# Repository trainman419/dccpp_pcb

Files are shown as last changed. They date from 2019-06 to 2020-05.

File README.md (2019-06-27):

# DCC++ PCB - All the parts for a basic DCC++ command station on a single PCB

This is the DCC++ board project. It's a relatively simple printed circuit board which integrates all of the components that are necessary for a DCC++ base station onto a single PCB, with all of the things you need, and nothing you don't.

Instead of the typical 1A limit of the arduino motor shield, this board uses the IFX007T half-bridge, with much larger current and voltage capability (up to 24V). Current capacity (without a heatsink) is probably around 5A, but may be more with proper ventilation or heatsinking.

The board is roughly based on the [Arduino Leonardo](https://www.arduino.cc/en/Main/Arduino_BoardLeonardo) and [Sparkfun's Pro Micro board](https://www.sparkfun.com/products/12640), but with the outputs already wired to the correct pins on IFX007T. The unused pins are available on screw terminals.

I designed this board to support the current and voltage needs of a G scale railroad, but it should work equally well for smaller scales.

The LEDs are connected to Arduino pins D1 and D2.

# Initial Programming

 * Attach an AVR ISP programming dongle, USBtiny, or other AVR programmer to your PC and board. (Make sure the drivers are installed).
 * Power on the DCC++ board by plugging in the micro USB cable.
 * Open the Arduino IDE
 * In the Tools menu, select "Arduino Leonardo" as the board type
 * In the Tools menu, select your programmer
 * In the Tools menu, select "Burn Bootloader"
 * Wait for the bootloader to complete. The board should show up as a serial port after the bootloader is flashed.
 * Clone my fork of the DCC++ project and load the DCCpp_Uno sketch onto the board.
 * Done!

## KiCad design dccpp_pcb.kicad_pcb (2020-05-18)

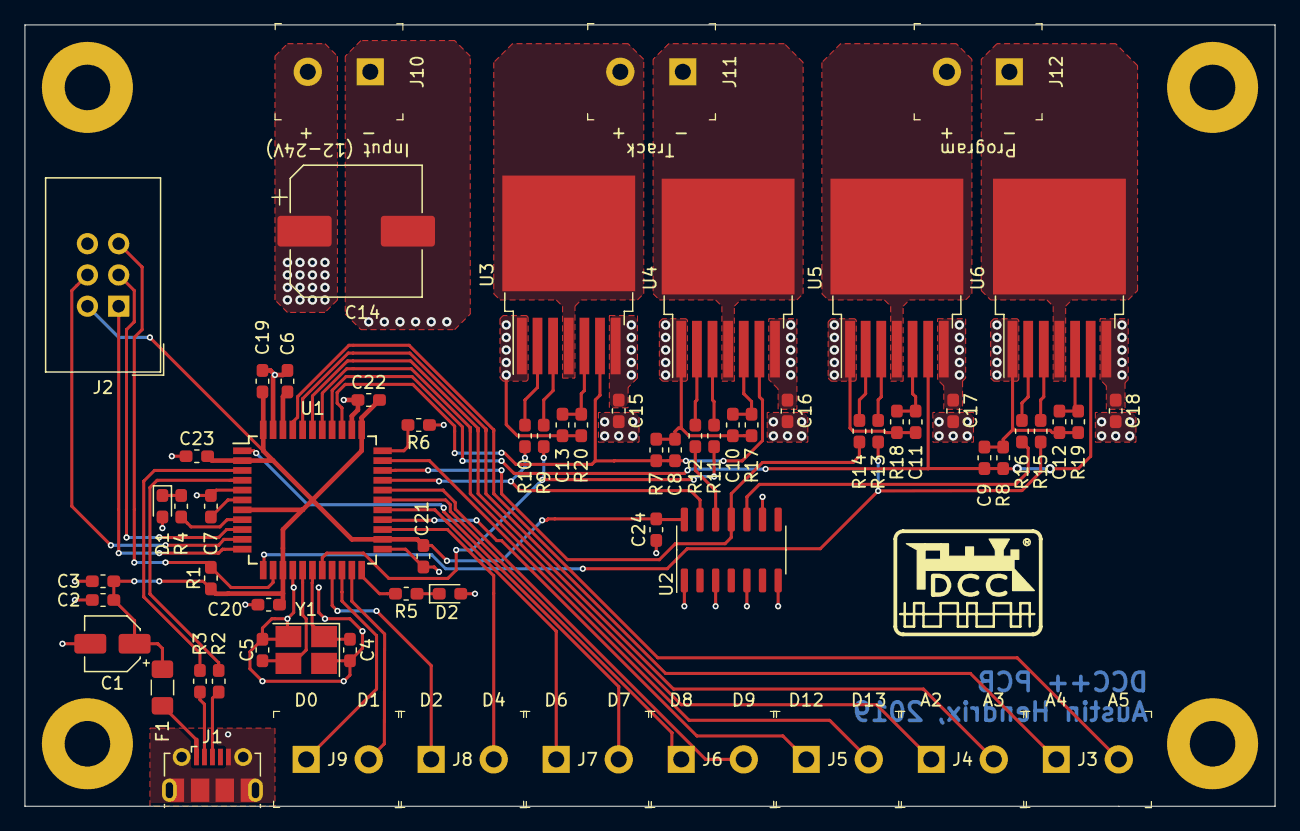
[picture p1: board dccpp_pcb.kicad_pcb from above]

Board: 2 copper layers, 101.6 x 63.5 mm, 66 parts (0 on the bottom side), 59 nets.

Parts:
C1: 10uF; CP_Elec_4x5.4
C2, C6, C10, C11, C12, C13, C19, C20, C21, C22, C23, C24: 0.1uF 10V; C_0603_1608Metric_Pad1.05x0.95mm_HandSolder
C3, C7: 1uF 10V; C_0603_1608Metric_Pad1.05x0.95mm_HandSolder
C4, C5: 22pF 10V; C_0603_1608Metric_Pad1.05x0.95mm_HandSolder
C8, C9: 1000pF 10V; C_0603_1608Metric_Pad1.05x0.95mm_HandSolder
C14: 100uF 30V; CP_Elec_10x10.5
C15, C16, C17, C18: 0.1uF 30V; C_0603_1608Metric_Pad1.05x0.95mm_HandSolder
D1: LED (Yellow); LED_0603_1608Metric_Pad1.05x0.95mm_HandSolder
D2: LED (Green); LED_0603_1608Metric_Pad1.05x0.95mm_HandSolder
F1: 500mA cont / 1A trip; Fuse_1206_3216Metric_Pad1.42x1.75mm_HandSolder
J1: USB_B_Micro; USB_Micro-B_Molex-105017-0001
J2: AVR-ISP-6; IDC-Header_2x03_P2.54mm_Vertical
J3, J4, J5, J6, J7, J8, J9, J10, J11, J12: OSTTC022162; Term_Block_1x2_P5.08MM
R1, R6, R9, R10, R11, R12, R13, R14, R15, R16: 10k; R_0603_1608Metric_Pad1.05x0.95mm_HandSolder
R2, R3: 22; R_0603_1608Metric_Pad1.05x0.95mm_HandSolder
R4, R5: 330; R_0603_1608Metric_Pad1.05x0.95mm_HandSolder
R7, R8: 470; R_0603_1608Metric_Pad1.05x0.95mm_HandSolder
R17, R18, R19, R20: 510; R_0603_1608Metric_Pad1.05x0.95mm_HandSolder
U1: ATmega32U4-AU; TQFP-44_10x10mm_P0.8mm
U2: 74HC04; SOIC-14_3.9x8.7mm_P1.27mm
U3, U4, U5, U6: IFX007T; TO-263-7_TabPin8
Y1: 16MHz; Crystal_SMD_SeikoEpson_TSX3225-4Pin_3.2x2.5mm_HandSoldering

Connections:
+5V: C1.1, C2.2, C3.2, C19.2, C20.2, C21.2, C22.2, C23.2, C24.2, F1.1, J2.2, R1.2, U1.2, U1.7, U1.14, U1.24, U1.34, U1.44, U2.14
/A2: J4.1, U1.38
/A3: J4.2, U1.39
/A4: J3.1, U1.40
/A5: J3.2, U1.41
/D0: J9.1, U1.20
/D1: J9.2, U1.21
/D2: J8.1, U1.19
/D4: J8.2, U1.25
/D6: J7.1, U1.27
/D7: J7.2, U1.1
/D8: J6.1, U1.28
/D9: J6.2, U1.29
/D12: J5.1, U1.26
/D13: J5.2, U1.32
/MISO: J2.1, U1.11
/MOSI: J2.4, U1.10
/OUT: R10.2, U1.30, U2.13
/OUT_EN: R9.2, R11.2, U1.18
/OUT_SENSE: C8.1, R7.1, U1.36, U3.6, U4.6
/PROG: R14.2, U1.31, U2.11
/PROG_EN: R13.2, R15.2, U1.12
/PROG_N: J12.1, U6.4, U6.8
/PROG_P: J12.2, U5.4, U5.8
/PROG_SENSE: C9.1, R8.1, U1.37, U5.6, U6.6
/RESET: J2.5, R1.1, U1.13
/SCK: J2.3, U1.9
/TRACK_N: J11.1, U4.4, U4.8
/TRACK_P: J11.2, U3.4, U3.8
GND: C1.2, C2.1, C3.1, C4.2, C5.2, C6.1, C7.1, C8.2, C9.2, C10.2, C11.2, C12.2, C13.2, C14.2, C15.2, C16.2, C17.2, C18.2, C19.1, C20.1, C21.1, C22.1, C23.1, C24.1, D1.2, D2.2, J1.5, J1.6, J2.6, J10.1, R6.1, R7.2, R8.2, R17.2, R18.2, R19.2, R20.2, U1.5, U1.15, U1.23, U1.35, U1.43, U2.1, U2.3, U2.5, U2.7, U2.9, U3.1, U4.1, U5.1, U6.1, Y1.2, Y1.4
unnamed: C4.1, U1.17, Y1.1
unnamed: C5.1, U1.16, Y1.3
unnamed: C6.2, U1.42
unnamed: C7.2, U1.6
unnamed: C10.1, R17.1, U4.5
unnamed: C11.1, R18.1, U5.5
unnamed: C12.1, R19.1, U6.5
unnamed: C13.1, R20.1, U3.5
unnamed: D1.1, R4.1
unnamed: D2.1, R5.1
unnamed: F1.2, J1.1
unnamed: J1.2, R3.2
unnamed: J1.3, R2.2
unnamed: R2.1, U1.4
unnamed: R3.1, U1.3
unnamed: R4.2, U1.8
unnamed: R5.2, U1.22
unnamed: R6.2, U1.33
unnamed: R9.1, U3.3
unnamed: R10.1, U3.2
unnamed: R11.1, U4.3
unnamed: R12.1, U4.2
unnamed: R12.2, U2.12
unnamed: R13.1, U5.3
unnamed: R14.1, U5.2
unnamed: R15.1, U6.3
unnamed: R16.1, U6.2
unnamed: R16.2, U2.10
VCC: C14.1, C15.1, C16.1, C17.1, C18.1, J10.2, U3.7, U4.7, U5.7, U6.7

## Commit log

2019-05-22 DCC++ PCB. ATMega32U4 + USB
    [dccpp_pcb.kicad_pcb, dccpp_pcb.sch]
2019-05-22 Add datasheets and 5V
    [dccpp_pcb.sch]
2019-05-22 Arduino side complete
    [dccpp_pcb.sch]
2019-05-22 Add symbol for IFX007T
    [dccpp_pcb.sch]
2019-05-22 Add most output circuitry
    [dccpp_pcb.sch]
2019-05-22 Add DCC++ pdf and current sense circuit
    [dccpp_pcb.sch]
2019-05-22 Fix ERC errors
    [dccpp_pcb.sch]
2019-05-22 Add digital connectors. Fixes most remaining ERC
    [dccpp_pcb.sch]
2019-05-22 Assign most footprints
    [dccpp_pcb.sch]
2019-05-22 Start assigning footprints and part numbers
    [dccpp_pcb.sch]
2019-05-22 More part numbers and footprints
    [dccpp_pcb.sch]
2019-05-22 Final part numbers
    [dccpp_pcb.sch]
2019-05-22 PCB created, placement mostly complete
    [dccpp_pcb.kicad_pcb]
2019-05-22 Setup design rules
    [dccpp_pcb.kicad_pcb, dccpp_pcb.sch]
2019-05-22 Cleanup of h-bridge layout
    [dccpp_pcb.kicad_pcb]
2019-05-22 More layout work
    [dccpp_pcb.kicad_pcb]
2019-05-22 Start work on signal layout.
    [dccpp_pcb.kicad_pcb, dccpp_pcb.sch]
2019-05-23 More routing.
    [dccpp_pcb.kicad_pcb]
2019-05-24 More routing
    [dccpp_pcb.kicad_pcb, dccpp_pcb.sch]
2019-05-31 More layout
    [dccpp_pcb.kicad_pcb]
2019-06-02 Routing almost complete
    [dccpp_pcb.kicad_pcb]
2019-06-02 Routing complete
    [dccpp_pcb.kicad_pcb]
2019-06-02 Clean up silkscreen
    [dccpp_pcb.kicad_pcb]
2019-06-04 Add DCC logo
    [dccpp_pcb.kicad_pcb]
2019-06-12 Working on board art
    [dccpp_pcb.kicad_pcb]
2019-06-12 Locomotive art!
    [dccpp_pcb.kicad_pcb]
2019-06-12 Finished art
    [dccpp_pcb.kicad_pcb]
2019-06-12 Clean up DCC logo
    [dccpp_pcb.kicad_pcb]
2019-06-26 Fix crystal
    [dccpp_pcb.kicad_pcb, dccpp_pcb.sch]
2020-05-18 Add IFX9201 datasheet, symbol and footprint
    [dccpp_pcb.kicad_pcb, dccpp_pcb.sch]
